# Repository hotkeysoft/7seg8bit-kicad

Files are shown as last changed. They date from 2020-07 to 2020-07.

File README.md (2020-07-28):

# Four-digit seven-segment indicator for 8 bit values
### Rev C August 2019
  - Reverse input protection
  - Real decimal mode w/four digits
  - Configurable modes via jumpers:
    - Decimal / HEX mode
      - Signed Decimal (-256-255)
      - Unsigned Decimal (0-255)
      - Hexadecimal (0-FF)
    - Latch mode
      - Latch value on L->H transition
      - Latch value on H->L transition
      - Unlatched (live display)  

*Note: This revision was produced and works*

### Rev B August 2019
  - Added programming header
  - Removed dim mode

*Note: Never produced*

### Rev A July 2019
- ATmega328P microcontroller running at 8MHz (internal clock)
- 2 digit 7-segment display
- Configurable modes via solder jumper:
  - HEX mode (default)
    - 00-FF
  - Pseudo-decimal
    - 00-99, .00-.99, ..00-..55 (dot = 100)
- Unlatched (live display)

Images
============
|Front | Back |
|---|---|
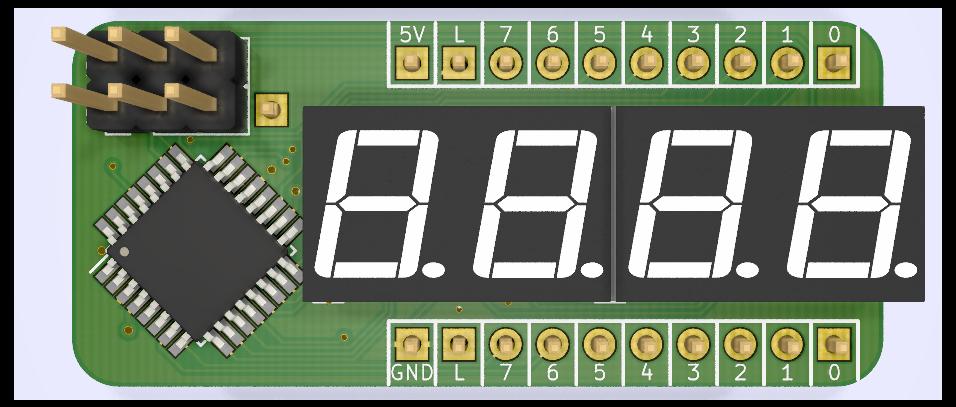
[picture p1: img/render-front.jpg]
Render Front
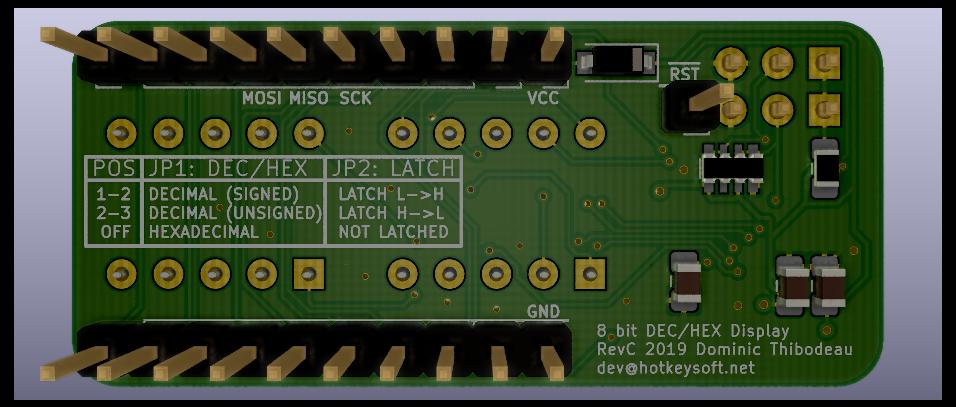
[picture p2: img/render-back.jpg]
Render Back
|||

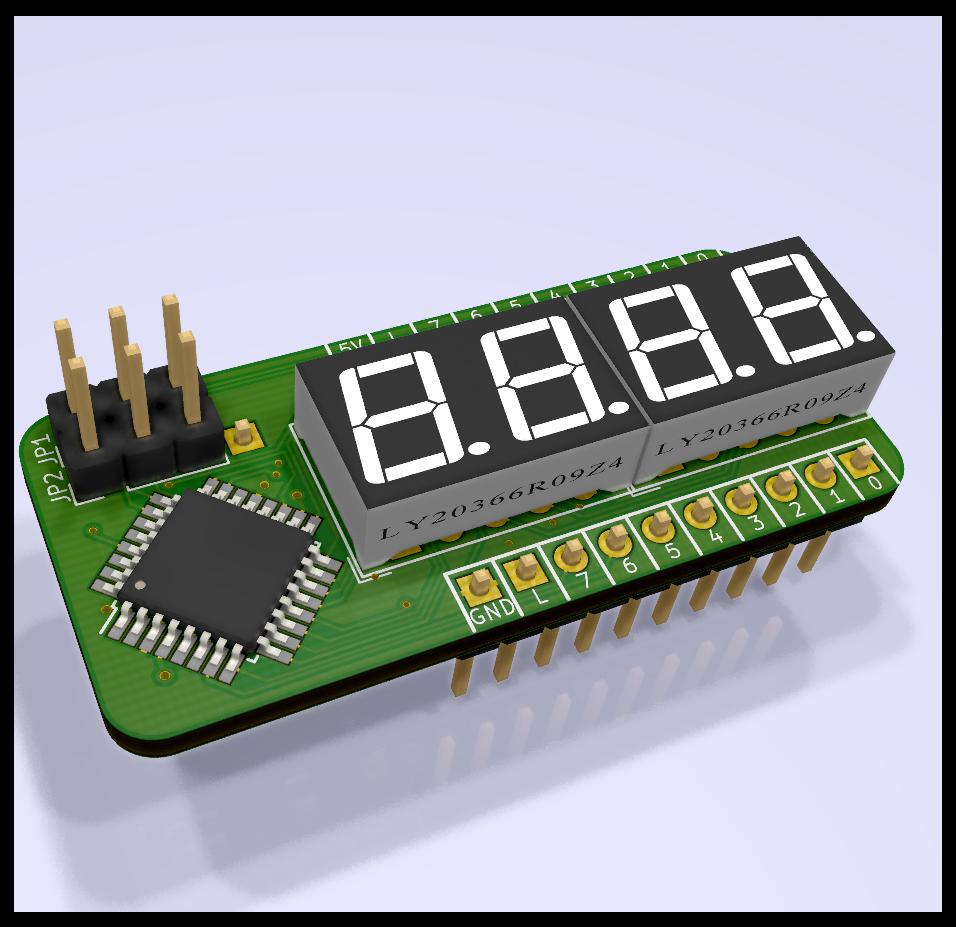
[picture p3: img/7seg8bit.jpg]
Render


### Schematics (pdf)
- [Complete schematics](./img/schema.pdf)

### PCB Images (svg)
- [Top](./img/pcb-front.svg)
- [Bottom](./img/pcb-back.svg)

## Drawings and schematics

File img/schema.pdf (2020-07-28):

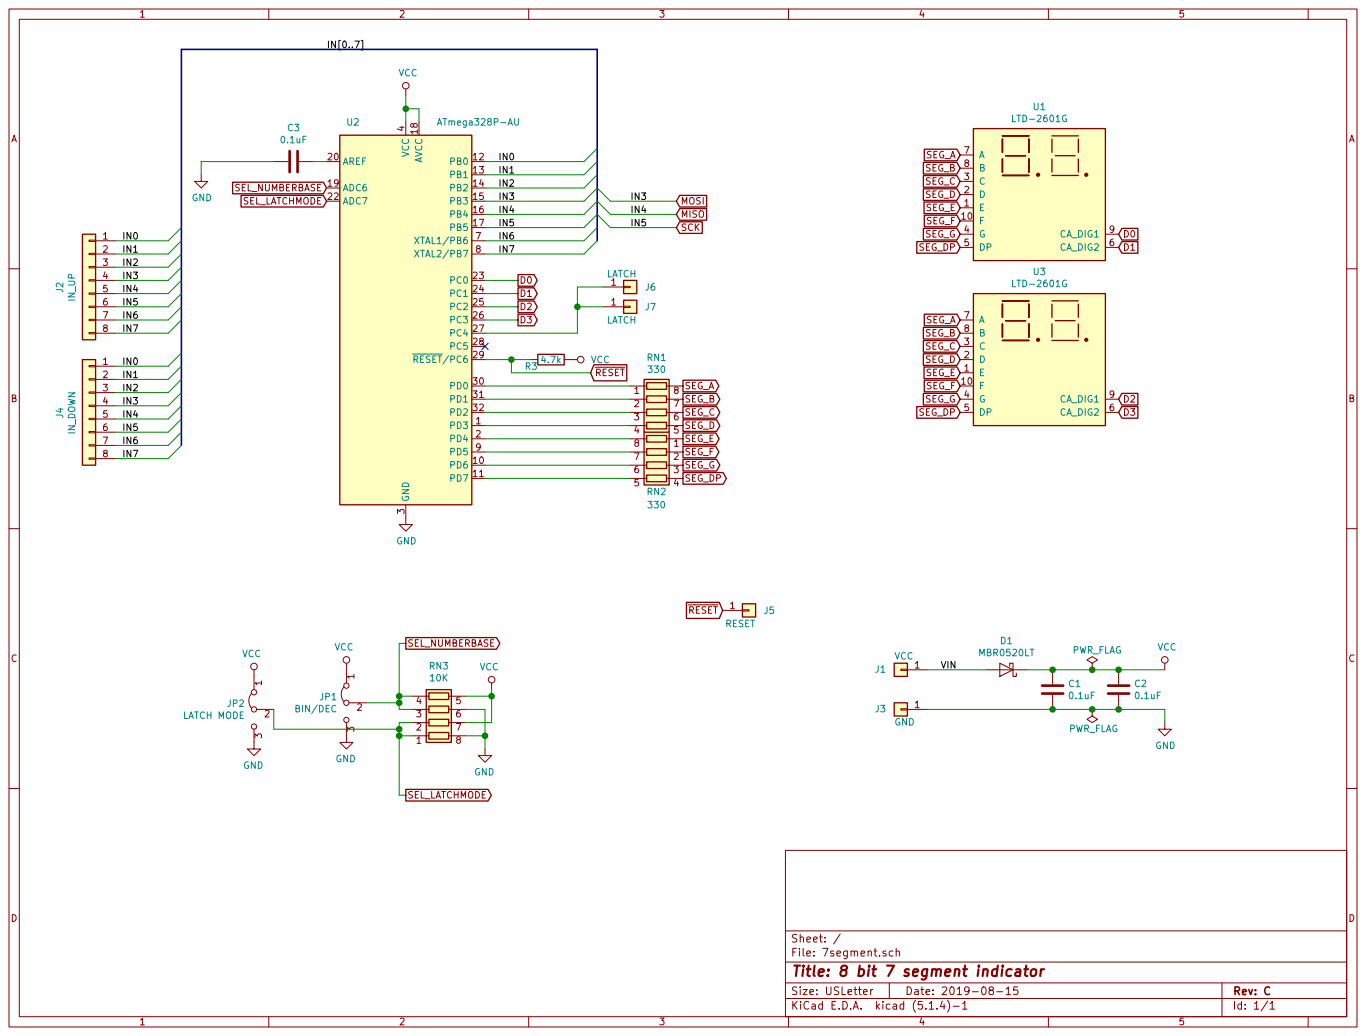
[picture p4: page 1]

Id: 1/1 Title: 8 bit 7 segment indicator

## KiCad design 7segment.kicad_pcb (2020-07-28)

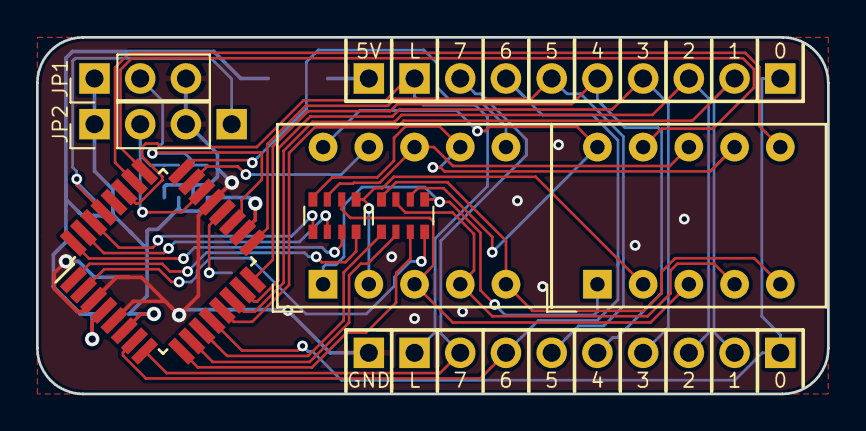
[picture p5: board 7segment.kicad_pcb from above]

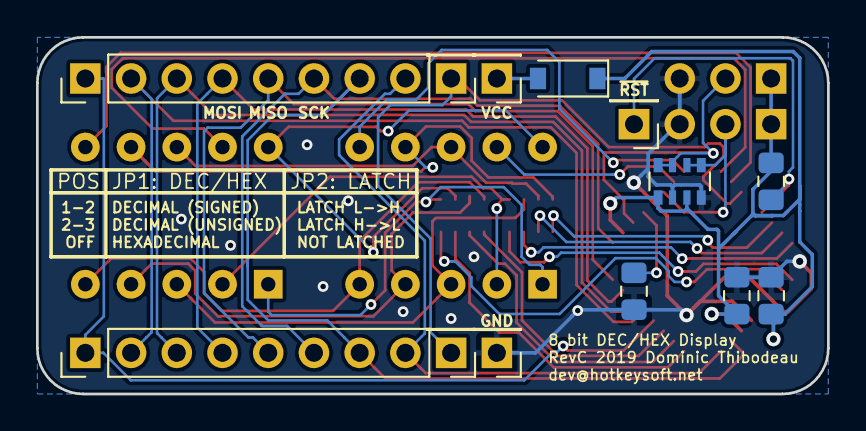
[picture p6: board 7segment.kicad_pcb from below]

Board: 2 copper layers, 43.9 x 19.8 mm, 20 parts (13 on the bottom side), 36 nets.

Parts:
C1, C2, C3: 0.1uF; C_0805_2012Metric_Pad1.15x1.40mm_HandSolder
D1: MBR0520LT; D_SOD-123
J1: VCC; PinHeader_1x01_P2.54mm_Vertical
J2: IN_UP; PinHeader_1x08_P2.54mm_Vertical
J3: GND; PinHeader_1x01_P2.54mm_Vertical
J4: IN_DOWN; PinHeader_1x08_P2.54mm_Vertical
J5: RESET; PinHeader_1x01_P2.54mm_Vertical
J6, J7: LATCH; PinHeader_1x01_P2.54mm_Vertical
JP1: BIN/DEC; PinHeader_1x03_P2.54mm_Vertical
JP2: LATCH MODE; PinHeader_1x03_P2.54mm_Vertical
R3: 4.7k; R_0805_2012Metric_Pad1.15x1.40mm_HandSolder
RN1, RN2: 330; R_Array_Convex_4x0603
RN3: 10K; R_Array_Convex_4x0603
U1, U3: LTD-2601G
U2: ATmega328P-AU; TQFP-32_7x7mm_P0.8mm

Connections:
/IN0: J2.1, J4.1, U2.12
/IN1: J2.2, J4.2, U2.13
/IN2: J2.3, J4.3, U2.14
/IN6: J2.7, J4.7, U2.7
/IN7: J2.8, J4.8, U2.8
/VIN: D1.2, J1.1
D0: U1.9, U2.23
D1: U1.6, U2.24
D2: U2.25, U3.9
D3: U2.26, U3.6
GND: C1.2, C2.2, C3.1, J3.1, JP1.3, JP2.3, RN3.6, RN3.8, U2.3, U2.5, U2.21
MISO: J2.5, J4.5, U2.16
MOSI: J2.4, J4.4, U2.15
unnamed: C3.2, U2.20
unnamed: J6.1, J7.1, U2.27
unnamed: RN1.1, U2.30
unnamed: RN1.2, U2.31
unnamed: RN1.3, U2.32
unnamed: RN1.4, U2.1
unnamed: RN2.5, U2.11
unnamed: RN2.6, U2.10
unnamed: RN2.7, U2.9
unnamed: RN2.8, U2.2
SCK: J2.6, J4.6, U2.17
SEG_A: RN1.8, U1.7, U3.7
SEG_B: RN1.7, U1.8, U3.8
SEG_C: RN1.6, U1.3, U3.3
SEG_D: RN1.5, U1.2, U3.2
SEG_DP: RN2.4, U1.5, U3.5
SEG_E: RN2.1, U1.1, U3.1
SEG_F: RN2.2, U1.10, U3.10
SEG_G: RN2.3, U1.4, U3.4
SEL_LATCHMODE: JP2.2, RN3.1, RN3.2, U2.22
SEL_NUMBERBASE: JP1.2, RN3.3, RN3.4, U2.19
VCC: C1.1, C2.1, D1.1, JP1.1, JP2.1, R3.1, RN3.5, RN3.7, U2.4, U2.6, U2.18
~RESET: J5.1, R3.2, U2.29

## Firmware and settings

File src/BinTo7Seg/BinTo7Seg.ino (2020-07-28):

/* Binary to 7 Segment display (8 bits)
 * Rev C 
 * 2019-08-17 Dominic Thibodeau
 * 
 * Modes: Hex / Signed Decimal / Unsigned Decimal
 *        Latched / Live
 *        
 * Target: ATmega328p
 */

/*
 * IN0-IN7: PB0-PB7
 * 
 * D0: PC0
 * D1: PC1
 * D2: PC2
 * D3: PC3
 * 
 * IN_LATCH: PC4
 * IN_DEBUG: PC5
 * 
 * SEGA-SEGDP: PD0-PD7
 * 
 * SEL_NUMBERBASE: ADC6
 * SEL_LATCHMODE: ADC7
 */

#define PA 0
#define PB 1
#define PC 2
#define PD 3

#define SEL_D0 14
#define SEL_D1 15
#define SEL_D2 16
#define SEL_D3 17

#define IN_LATCH 18

#define SEL_NUMBERBASE A6
#define SEL_LATCHMODE A7

const int digitDelay = 2;

bool triggeredOnce = false;
int lastLatchPinState;
byte latchedInput = 0;

enum DIGIT {
  DIGIT_D0 = SEL_D0,
  DIGIT_D1 = SEL_D1,
  DIGIT_D2 = SEL_D2,
  DIGIT_D3 = SEL_D3,
};

enum LATCHMODE {
  LATCH_LH,
  LATCH_HL,
  LATCH_LIVE
};

enum NUMBERBASE {
  NB_SIGNED_DEC,
  NB_UNSIGNED_DEC,
  NB_HEX
};

LATCHMODE getLatchMode() {
  int value = analogRead(SEL_LATCHMODE);
  if (value < 300)
    return LATCH_LH;
  else if (value > 700)
    return LATCH_HL;
  else 
    return LATCH_LIVE;  
}

NUMBERBASE getNumberBase() {
  int value = analogRead(SEL_NUMBERBASE);
  if (value < 300)
    return NB_SIGNED_DEC;
  else if (value > 700)
    return NB_UNSIGNED_DEC;
  else 
    return NB_HEX;      
}

void setup() {
  // Segments
  portMode(PD, OUTPUT);
  // Inputs
  portMode(PB, INPUT);

  pinMode(SEL_D0, OUTPUT);
  pinMode(SEL_D1, OUTPUT);
  pinMode(SEL_D2, OUTPUT);
  pinMode(SEL_D3, OUTPUT);

  pinMode(IN_LATCH, INPUT_PULLUP); //TODODT: remove pullup in prod  
  lastLatchPinState = digitalRead(IN_LATCH);
}

const PROGMEM byte digits[17] = {
  0b00111111, // 0
  0b00000110, // 1
  0b01011011, // 2  
  0b01001111, // 3
  0b01100110, // 4
  0b01101101, // 5
  0b01111101, // 6
  0b00000111, // 7 
  0b01111111, // 8
  0b01101111, // 9 
  0b01110111, // A
  0b01111100, // b
  0b00111001, // C
  0b01011110, // d
  0b01111001, // E
  0b01110001, // F
  0b01000000  // -
};

void outputBlank(DIGIT pos) {
  clearDigits();
  portWrite(PD, 255);
  selectDigit(pos);
}

void outputMinus(DIGIT pos) {
  clearDigits();
  portWrite(PD, ~pgm_read_byte_near(digits + 16));
  selectDigit(pos);  
}

void outputDigit(const byte digit, DIGIT pos) {
  clearDigits();
  if (digit > 15) return;
  portWrite(PD, ~pgm_read_byte_near(digits + digit));
  selectDigit(pos);    
}

void clearDigits() {
  digitalWrite(SEL_D0, LOW);
  digitalWrite(SEL_D1, LOW);
  digitalWrite(SEL_D2, LOW);
  digitalWrite(SEL_D3, LOW);
}

void selectDigit(DIGIT digit) {
  digitalWrite(digit, HIGH);
}

void outputNumberHex(const uint8_t number) {
  outputBlank(DIGIT_D0);
  delay(digitDelay);

  outputBlank(DIGIT_D1);
  delay(digitDelay);
  
  outputDigit(number >> 4, DIGIT_D2);
  delay(digitDelay);

  outputDigit(number&0x0F, DIGIT_D3);
  delay(digitDelay);
}

void outputNumberUnsignedDecimal(uint8_t number) {
  if (number > 99) {
    outputDigit(number/100, DIGIT_D1);
  } else {
    outputBlank(DIGIT_D1);
  }
  delay(digitDelay);  

  if (number > 9) {
    outputDigit((number/10)%10, DIGIT_D2);
  } else {
    outputBlank(DIGIT_D2);    
  }
  delay(digitDelay);
  
  outputDigit(number%10, DIGIT_D3);
  delay(digitDelay);
}

void outputNumberSignedDecimal(uint8_t number) {
  if (number > 127) {
    uint8_t unsignedValue = -number;

    outputNumberUnsignedDecimal(unsignedValue);  

    if (unsignedValue > 99)
      outputMinus(DIGIT_D0);
    else if (unsignedValue > 9)
      outputMinus(DIGIT_D1);
    else 
      outputMinus(DIGIT_D2);

    delay(digitDelay);
  } else {
    outputNumberUnsignedDecimal(number);
  }
}

void outputNumber(uint8_t number) {
    switch(getNumberBase()) {
      case NB_SIGNED_DEC:
        outputNumberSignedDecimal(number);
        break;
      case NB_UNSIGNED_DEC:
        outputNumberUnsignedDecimal(number);
        break;
      default:
        outputNumberHex(number);
    }
}

void loop() { 
  clearDigits();
  
  LATCHMODE latchMode = getLatchMode();

  if (latchMode != LATCH_LIVE) {
    bool triggered = false;
    int currLatchState = digitalRead(IN_LATCH);
    triggered = ((latchMode == LATCH_LH) && !lastLatchPinState && currLatchState) || 
      ((latchMode == LATCH_HL) && lastLatchPinState && !currLatchState);
    lastLatchPinState = currLatchState;

    if (triggered) {
      triggeredOnce = true;
      latchedInput = portRead(PB);
    }
    if (triggeredOnce) {
      outputNumber(latchedInput);
    }
  } else {   
    outputNumber(portRead(PB));
  }
}

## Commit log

2019-07-22 Initial import
    [7segment-B.Cu.gbr, 7segment-B.Mask.gbr, 7segment-B.SilkS.gbr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]
2020-07-28 Cleanup, added images
    [7segment.kicad_pcb]
2020-07-28 Revision B
    [7segment-B.Cu.gbr, 7segment-B.Mask.gbr, 7segment-B.SilkS.gbr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]
2020-07-28 Rev C
    [7segment-B.Cu.gbr, 7segment-B.Mask.gbr, 7segment-B.SilkS.gbr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]
